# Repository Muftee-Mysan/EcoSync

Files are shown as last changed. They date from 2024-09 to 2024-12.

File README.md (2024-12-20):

# ECOSYNC: Smart Energy Solution for Hotels

ECOSYNC is an innovative energy-saving solution tailored for the hotel industry. Our system bridges the gap between energy efficiency and guest comfort, addressing key challenges faced by hotels in managing air conditioning systems effectively.

---

## Problem Statement

Hotels often struggle to balance energy efficiency with guest comfort:
- **Keycard Systems** save energy but leave rooms uncomfortably warm for returning guests.
- **Keeping AC On** ensures comfort but wastes energy significantly.

### Our Solution
ECOSYNC optimizes energy usage by dynamically adjusting the air conditioning:
- When the keycard is **removed**, the AC temperature rises to conserve energy without causing discomfort.
- Upon **insertion**, the AC restores the initial, lower temperature for guest comfort.

---

## Key Features

- **Dual PCB Design**: Separate units for Keycard Presence Detection (KPD) and AC Control (ACC).
- **Bluetooth Communication**: Reliable, cost-effective signal exchange between KPD and ACC.
- **Energy Efficiency Modes**:
  - *Eco Mode*: Sets temperature to 25°C (indicated by a green LED).
  - *Luxury Mode*: Sets temperature to 23°C (indicated by a blue LED).
- **IR Sensors**: Detect keycard presence and transmit relevant signals to the AC.
- **Customizable Calibration**: Tailored implementation for each hotel room's air conditioning unit.

---

ecosyn final

## Technical Details

### Components Used
- **Microcontroller**: ATmega328P-PU
- **Bluetooth Modules**: HC-05 & HC-06
- **IR Proximity Sensor**: Detects keycard presence
- **IR Emitter**: Transmits AC temperature adjustment signals
- **Power Supply**: DC-DC Buck Converter with 3.7V rechargeable batteries

ECOSYNC has two seperate units
### 1. **Keycard Presence Detector (KPD)**
   - The KPD unit is a keycard holder equipped with an IR proximity sensor.
   - **Functionality**: 
     - Detects when the keycard is inserted or removed.
     - Sends a signal to the AC Controller (ACC) via Bluetooth when the keycard is removed.

### 2. **AC Controller (ACC)**
   - The ACC receives the signal from the KPD and adjusts the AC settings based on the mode selected.
   - **Modes**:
     1. **Eco Mode**:
        - Temperature is raised to 25°C.
        - Green LED indicates the Eco Mode is active.
     2. **Luxury Mode**:
        - Temperature is raised to 23°C.
        - Blue LED indicates the Luxury Mode is active.
   - The mode selection is manual and can be controlled by the hotel management.

---

## Future Improvements

- **IoT Integration**: Upgrade to Xtensa LX6 microprocessor for Wi-Fi and Bluetooth capabilities.
- **Mobile Automation**: Control via a dedicated app.
- **AI Scheduling**: Personalized temperature adjustments based on user behavior.
- **Voice Control**: Integration with virtual assistants for enhanced convenience.
- **Air Quality Enhancements**: Address CO2 levels with advanced ventilation systems.

---

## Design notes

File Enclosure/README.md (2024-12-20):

### Enclosure Design
The enclosures were designed to ensure durability, aesthetic appeal, and ease of integration:
- **Material**: 3D-printed plastic for lightweight and customizable builds.
- **Features**:
  - Compact housing for PCB components.
  - Openings for LED indicators, keycard slot, and connectors.
  - Sleek design to blend seamlessly into hotel room decor.

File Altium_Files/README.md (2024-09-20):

### Altium PCB Design Files

We have used **Altium Designer** to create the printed circuit board (PCB) designs for our project. The files in this directory include the **schematic** and **PCB layouts** for two specific designs:

1. **AC Controller**
2. **Key Card Presence Detector**

#### Design Details:

- Both PCBs were designed using a **two-layer** approach, with **top** and **bottom** layers.
- During the design process, we referred to the **datasheets** of all the components to ensure accurate specifications and proper functionality.

These designs are crucial for controlling the air conditioning system and detecting key card presence, contributing to energy efficiency and automated room control in our project.

pcb

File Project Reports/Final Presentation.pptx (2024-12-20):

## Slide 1

SocketBurners
Aashir MRM
220004M
Muftee MMM
220399B
Munavvar MAA
220405T
Nadha MI
220409J

EcoSync
“Enhancing Comfort, Conserving Power, Innovating the Future”
Intelligent AC Temperature Regulator

EN1190 – Engineering Design Project

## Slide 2

The Problem

“Energy Wastage due to lack of optimization in luxurious hotels.”

User leaves
the hotel room with
the keycard

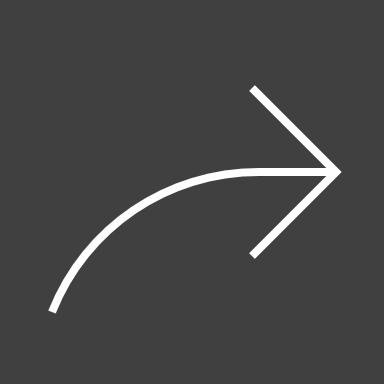
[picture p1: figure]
Back outline

Cut the power
to the room while
Keeping the AC running

1

Waste of Energy

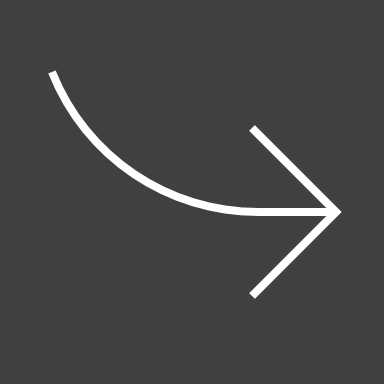
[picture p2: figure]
Back outline

Cut the entire
power supply

2

User discomfort
upon arrival

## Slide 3

The Solution

A compromise between visitor comfort and energy usage is required.
To accomplish this, we present to you

EcoSync
“Enhancing Comfort, Conserving Power, Innovating the Future”
Intelligent AC Temperature Regulator

ECOSYNC regulates the air conditioning system based on user presence.

The Beneficiary

Luxurious Hotel chains
&
The people of Sri Lanka

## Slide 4

Designing the Solution

The Concept
Breadboard Implementation
PCB Design
Enclosure Design
Assembly

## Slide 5

Problem Validation
Hotel Visit: Sofia Colombo

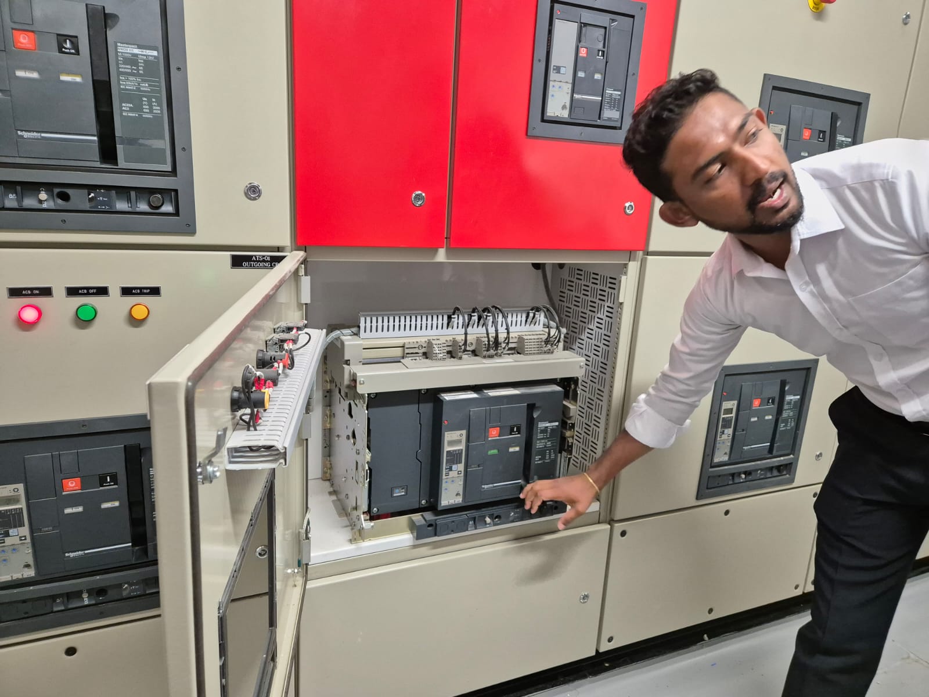
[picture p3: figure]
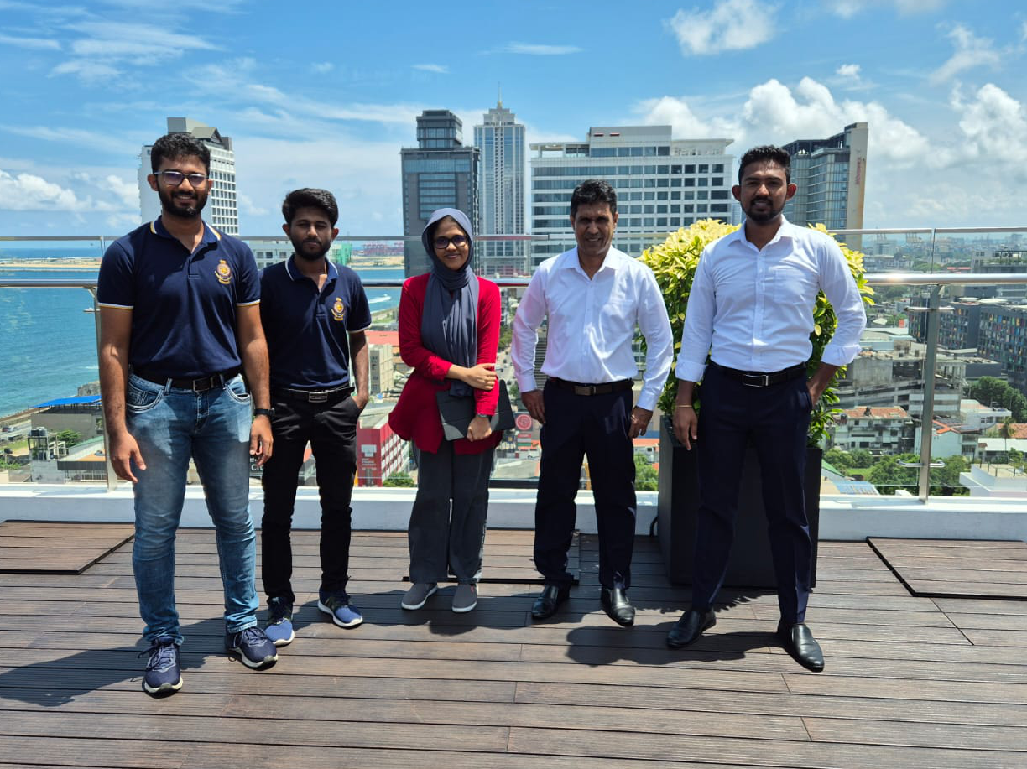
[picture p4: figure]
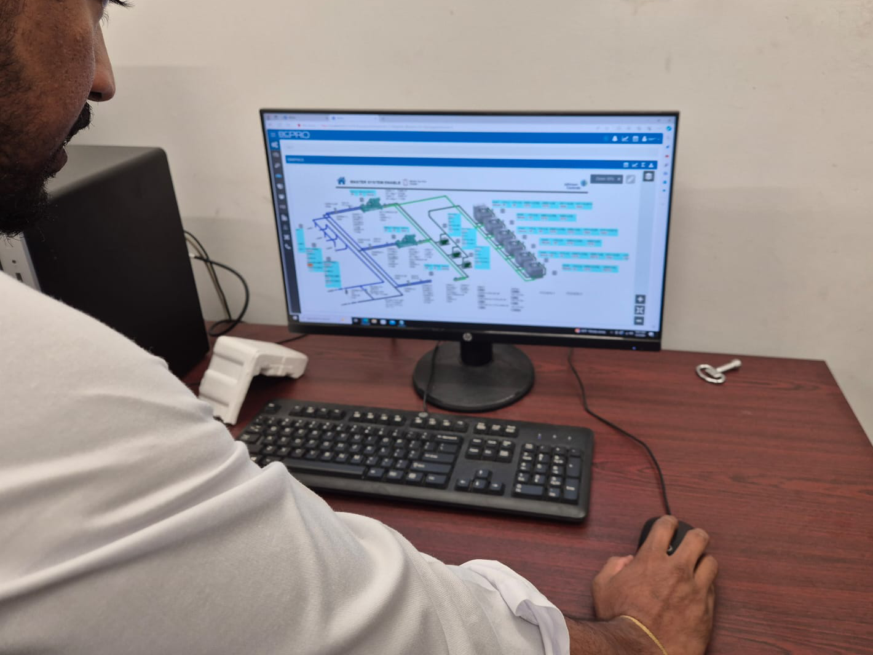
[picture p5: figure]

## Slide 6

Block Diagram of the Concept

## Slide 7

Functionality

ECOSYNC is a combination of two separate units
1. KPD: Keycard Presence Detector
2. ACC: Air Conditioner Controller

KPD

When the Keycard is removed, (Person Left the room)

The relevant IR signals are sent to the AC

ACC

Eco Mode: Temperature rises to 25°C
Luxury Mode: Temperature rises to 23°C

The message gets transmitted to ACC through Bluetooth

The ACC receives the message

Preset by hotel management

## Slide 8

The PCB Design
ACC

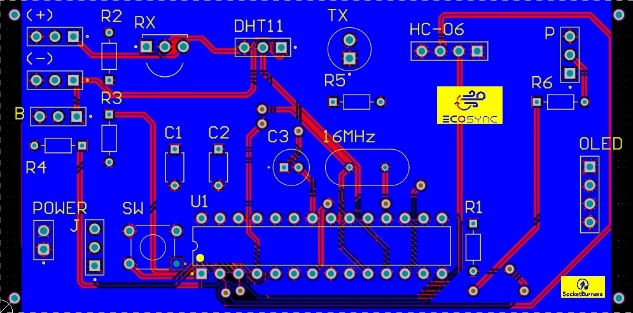
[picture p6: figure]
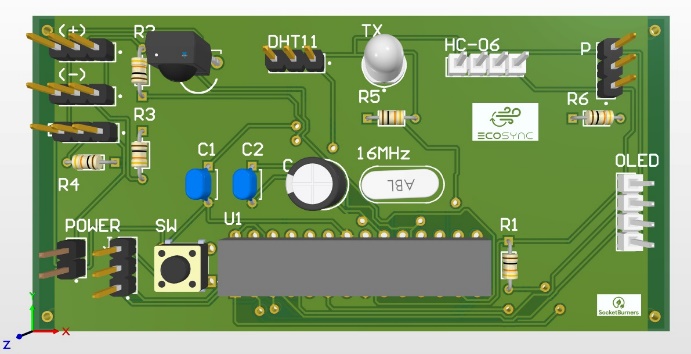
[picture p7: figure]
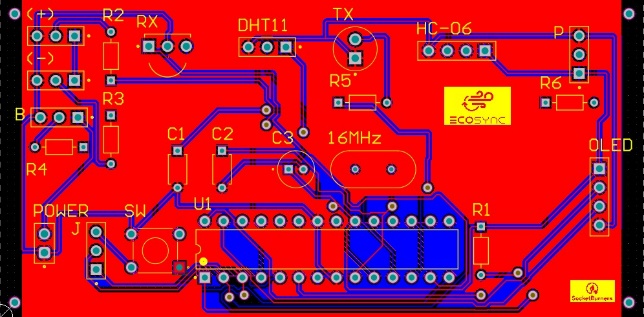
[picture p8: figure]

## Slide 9

The PCB Design
KPD

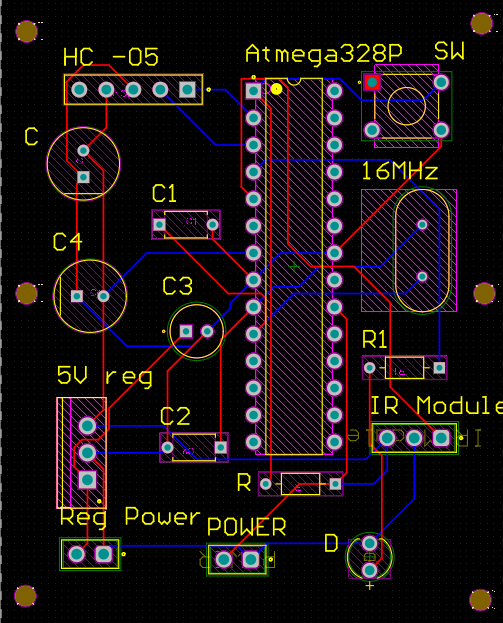
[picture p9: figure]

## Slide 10

The Enclosure Design
ACC

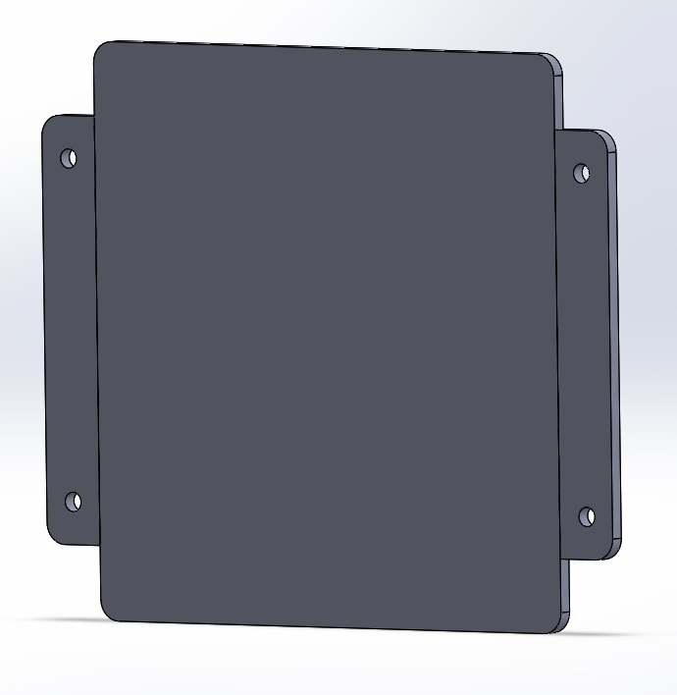
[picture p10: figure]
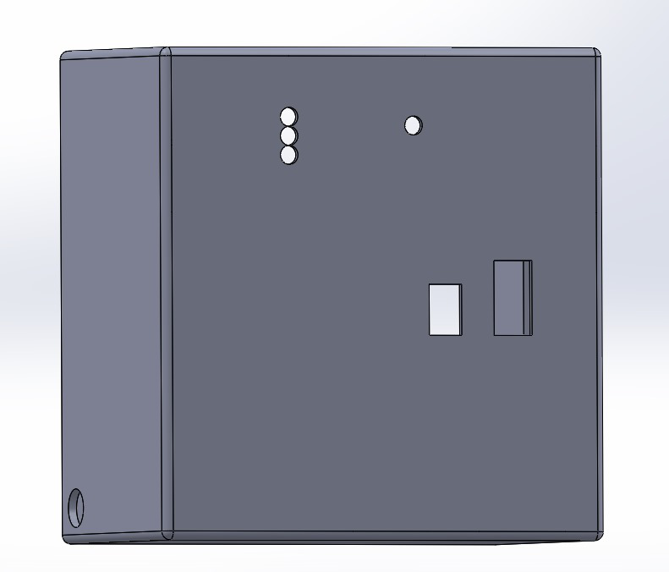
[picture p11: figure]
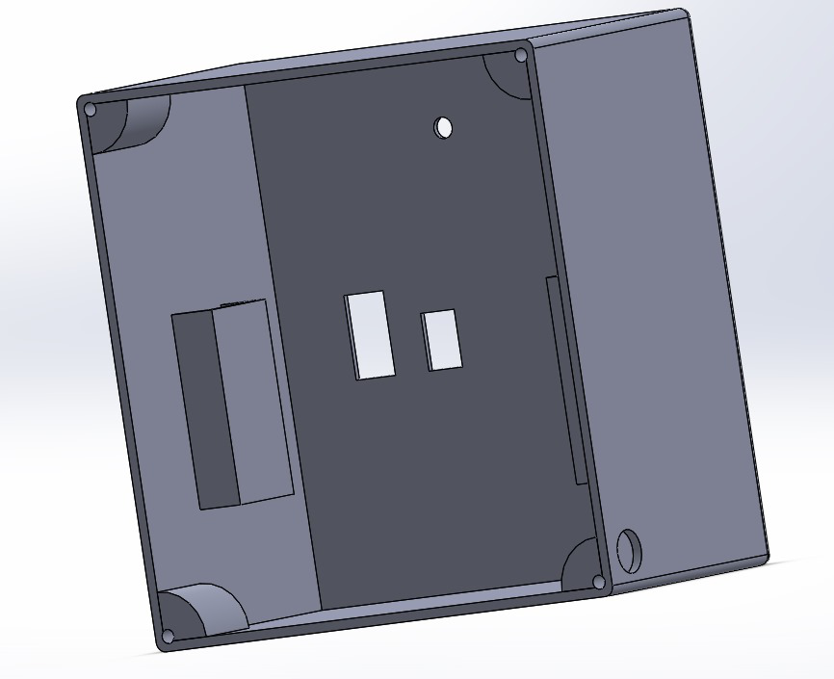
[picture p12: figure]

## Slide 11

The Enclosure Design
KPD

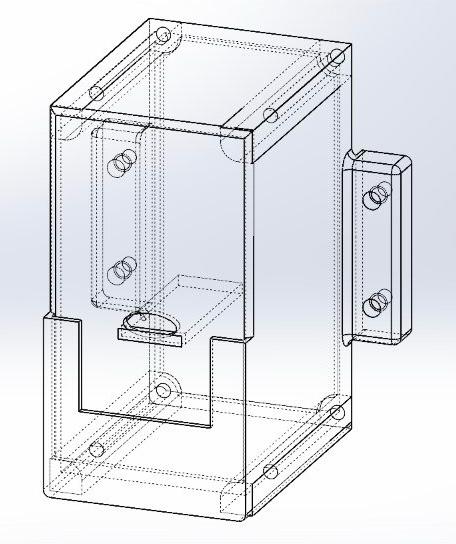
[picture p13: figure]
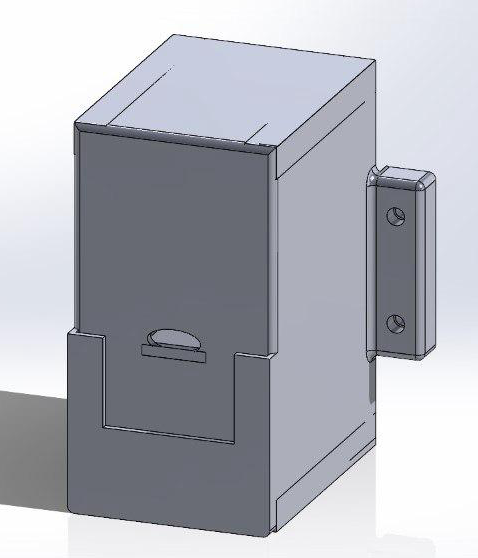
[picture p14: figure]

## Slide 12

The Assembly

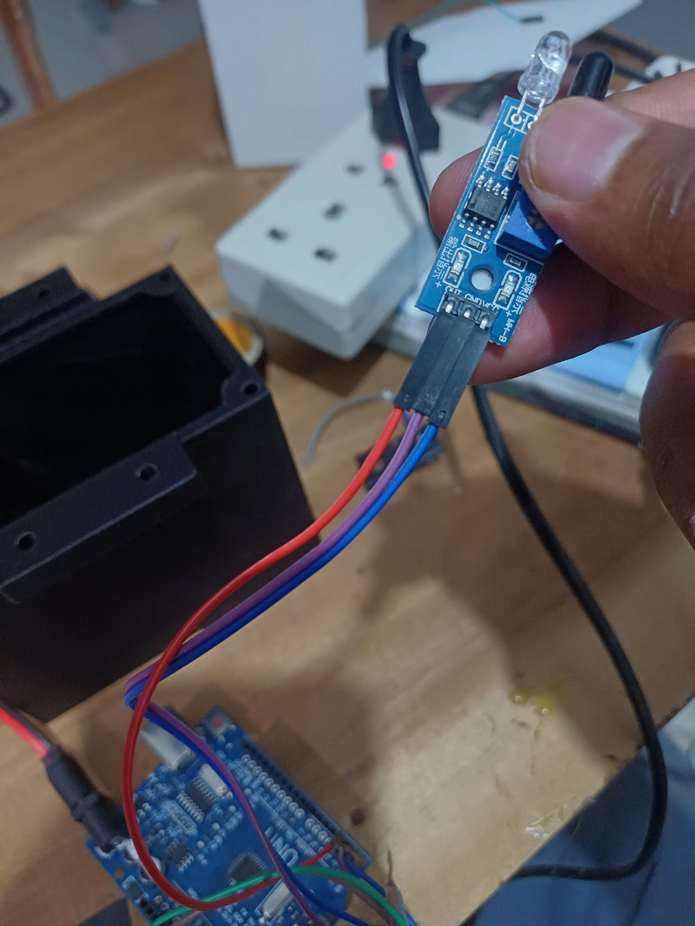
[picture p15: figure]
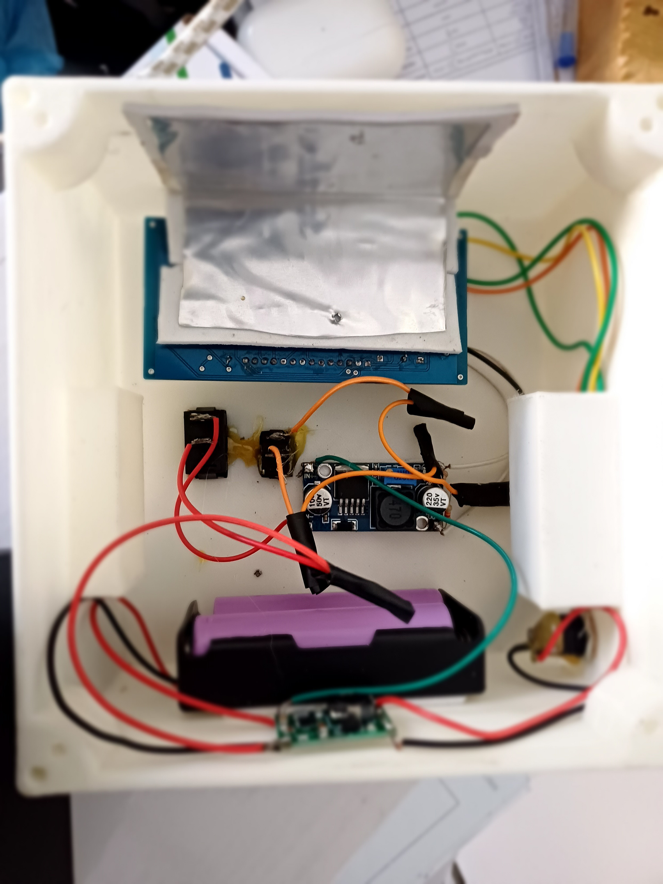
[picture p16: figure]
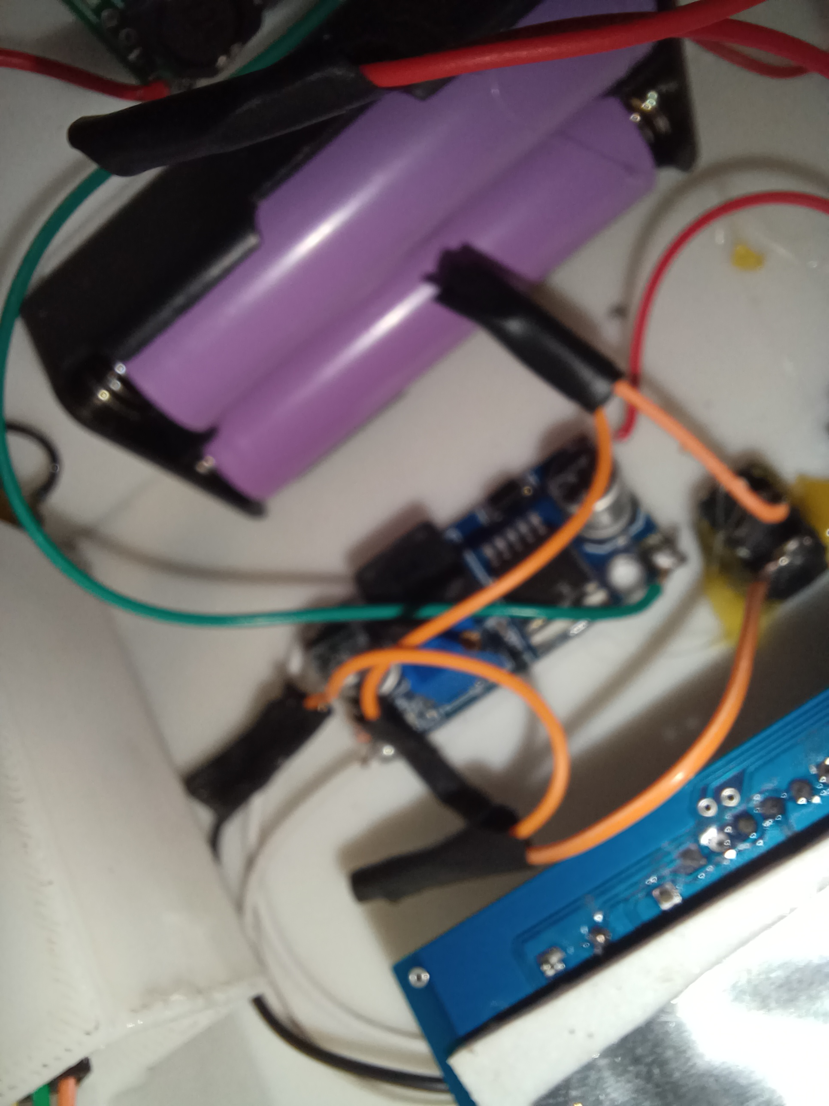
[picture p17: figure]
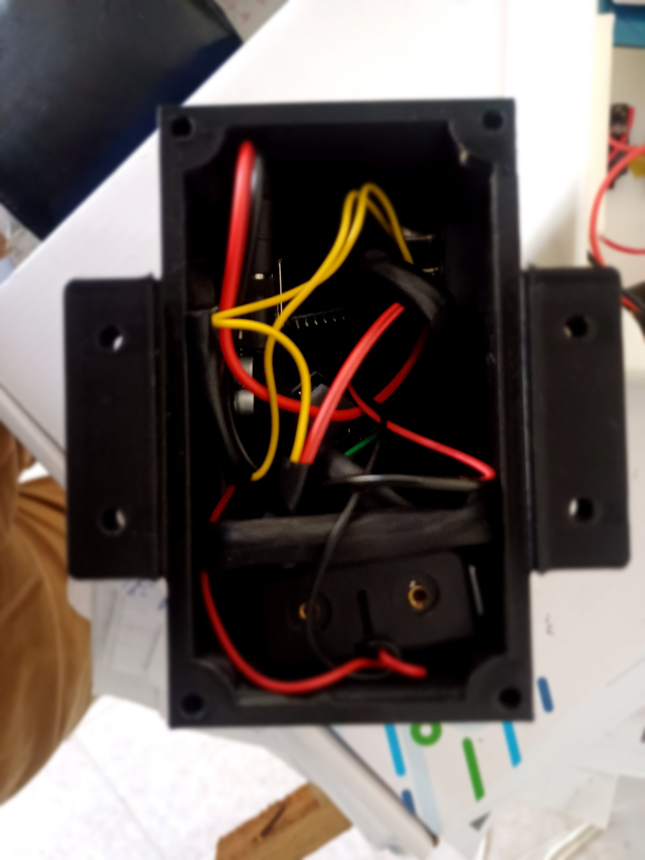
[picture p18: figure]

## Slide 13

The Final Product

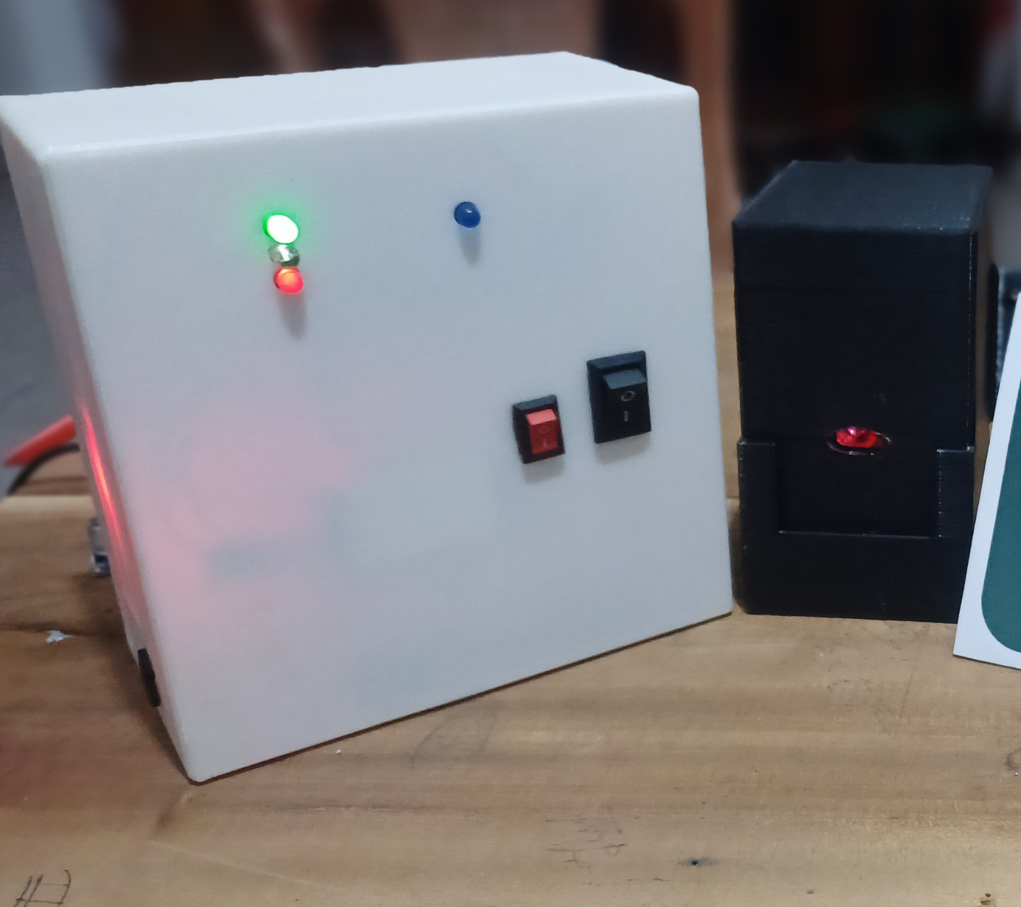
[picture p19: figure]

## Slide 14

Our Website

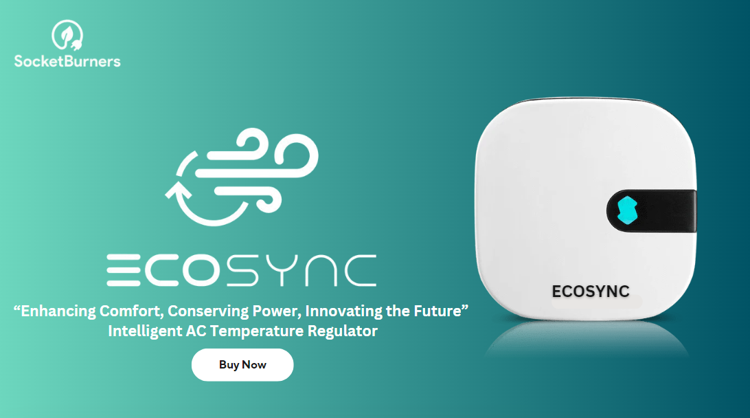
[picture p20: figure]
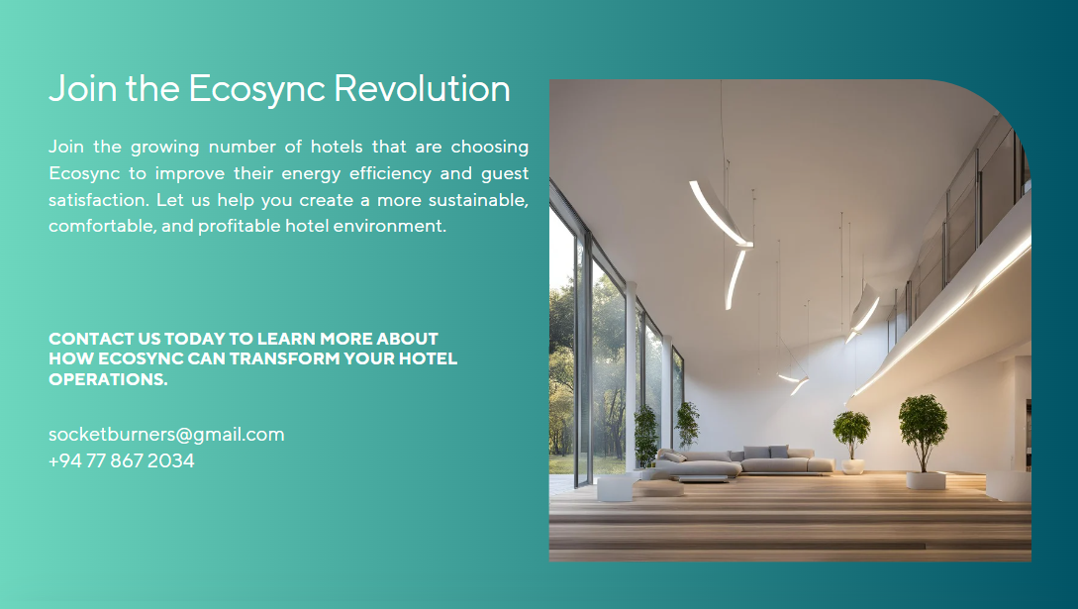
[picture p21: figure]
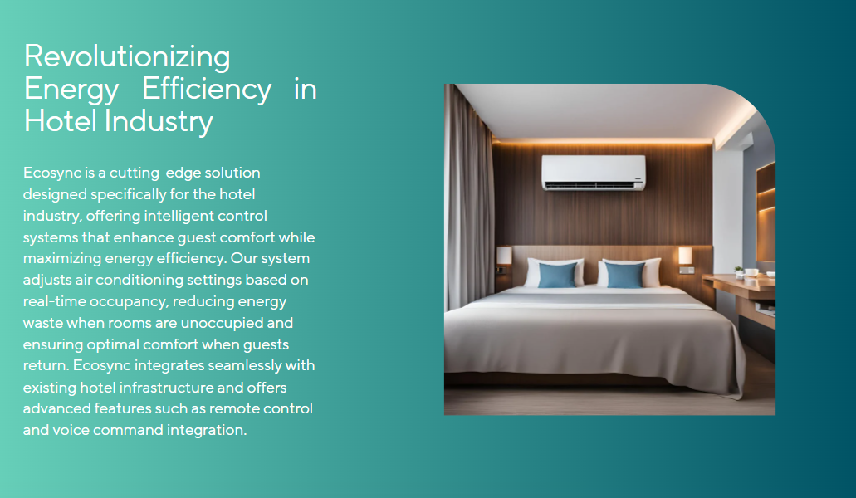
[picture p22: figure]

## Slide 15

Project Budget

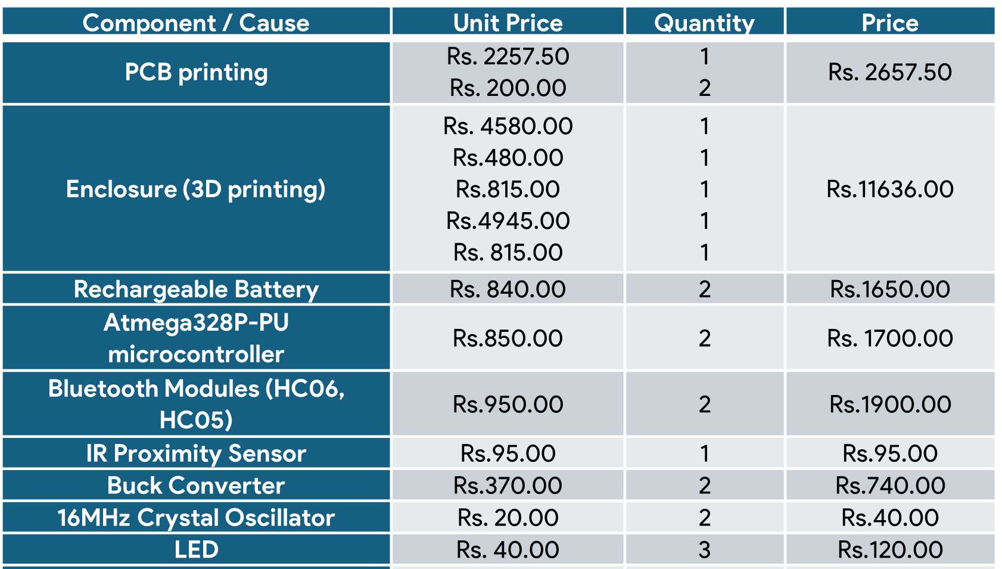
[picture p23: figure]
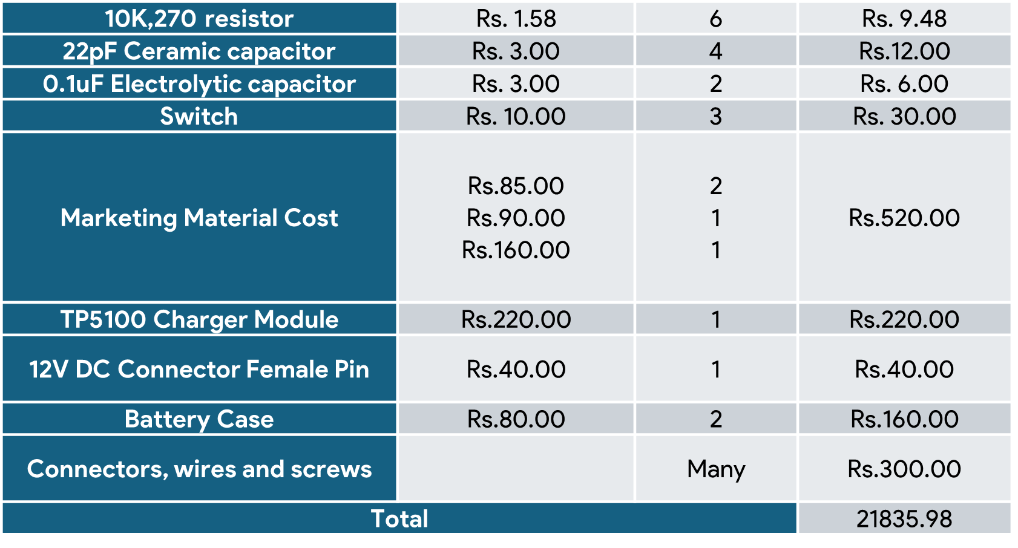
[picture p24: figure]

Rs.21835.98

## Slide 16

Task Delegation

TASK | ALLOCATED MEMBER(S)
Finding a problem | ALL
Solution plan | ALL
Circuit Diagrams | Muftee MMM Aashir MRM
PCB design | Nadha MI
Programming and coding the controller | Aashir MRM
Enclosure design | Muftee MMM
Product assembly | Aashir MRM Munavvar MAA
Documentation Preparations | Munavvar MAA Nadha MI
Brand design | Munavvar MAA
Web Page Design | Nadha MI

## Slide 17

The Team
SocketBurners

Aashir MRM
220004M

Munavvar MAA
220405T

Muftee MMM
220399B

Nadha MI
220409J

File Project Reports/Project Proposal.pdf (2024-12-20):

# Project Proposal


# EcoSync

“Enhancing Comfort, Conserving Power, Innovating the Future”

### Intelligent AC Temperature Regulator

## SocketBurners

Aashir MRM
220004M

Muftee MMM
220399B

Munavvar MAA
220405T

Nadha MI
220409J

EN1190 – Engineering Design Project

One of the major concerns in today's industrial world is the energy deficit. This brings various challenges to energy consumption due to rising energy costs & wastage.
Hotels have implemented a key card system that automatically switches off the electricity when guests leave their rooms to conserve energy. However, upon returning to their rooms, guests often experience discomfort due to the temperature rise and must manually adjust the air conditioner. However, some hotels keep the air conditioner running even after removing the key card to ensure guest comfort, leading to significant energy wastage.
As an effective solution for this problem, we came up with the idea: “EcoSync.”

which adjusts the AC level without turning it off based on the presence of guests as a practical solution to optimize energy usage while maintaining guests’ comfort.

The standard temperature range for air conditioners when the user is present in the room is typically between 18 to 20 degrees Celsius.
When the keycard is removed, the ECOSYNC system will automatically adjust the AC temperature to a higher level around 27-28 degrees Celsius. This feature can help save energy consumption by up to 50% - 70%. Once the Keycard is inserted again, the system will automatically return to the initial lower temperature levels.
It prevents user discomfort and at the same time conserves energy.
Introduction | Concept
1. Check whether the keycard is inserted or not.
2. Send the signal to the controller’s receiver.
3. Emit the IR rays from the controller to the AC’s IR receiver to change the temperature.
4. Send data to the Cloud Network.

## Implementation Objectives

1. PCB with Controller
2. 2 Transceivers
3. An IR Emitter
4. A Wi-Fi Microchip
5. Power Supply

## Resources

Target Scope:
We mainly focus to establish a market in the luxury hotel field where the keycard system is in use. Expected Outcome:
Reducing nation’s energy wastage.
(Offering high quality customer service in the hotel industry)

## Expected Scope and Outcome

# EcoSync |

Air Conditioner
System

Product Description
Ecosync is a smart A/C regulator designed to be used in luxurious hotels. Its primary function is to maintain the A/C temperature at an optimum level (i.e: A level at which both user comfort and energy usage are considered)
Problem Validation
- Sri Lanka’s point of view.
Sri Lanka is going through unprecedented times. The economic crisis continues to worsen on one side and on the other side we have a shortage of energy supply to meet current energy demands. Amidst this status quo, it's imperative for us as a nation to do everything possible to preserve energy and to impose regulations to mitigate energy wastage. Therefore, it is in the best interest of the country to have regulations in place to control energy usage in luxurious hotels. In this context, our solution comes in handy since our proposed solution cuts down energy used by the air conditioning system by 50 %. This creates a huge incentive for hotels to consider our product.
- Energy Regulations set by the government.
Hotels must follow energy regulations that aim to promote sustainability and reduce environmental impact. These regulations cover different aspects like energy efficiency standards, renewable energy utilization, and energy conservation measures. Hotels are required to meet specific standards for lighting, AC systems, and appliances.
- Global point of view.
Sustainable Development Goal 7 (SDG7) calls for “affordable, reliable, sustainable and modern energy for all” by 2030. The world collectively is promoting measures to achieve sustainable energy. Through our product, we can conserve valuable energy.
In addition, hotels are also incentivized by this. They can earn tax benefits, be nominated for awards, etc... for demonstrating sustainable practices. This is a win-win for our proposed solution.
- Luxury Hotels’ point of view.
The hotels that are under consideration here are in the business for money. They look for ways to increase their profits. While having to abide by government regulations, promote an eco-friendly image, and strive to achieve UN sustainability goals are within the Hotel’s mandate, there is something else that interests them more, which is profit. This is where we come into the picture. As per the tariff approved by the Public Utilities Commission of Sri Lanka, hotels are charged 25 LKR/kWh for energy consumption between 0-180 kWh, and 36 LKR/kWh for energy consumption above 180 kWh. This leads to a fourfold increase in the monthly charge.
Reference: https://www.pucsl.gov.lk/electricity/tariff/industrial-consumers/

By cutting down the energy consumption by 52% using our product, we can bring down the costs by more than 50%. This is extremely beneficial for these hotels, which in turn creates demand for our product.

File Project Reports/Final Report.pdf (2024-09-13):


## University of Moratuwa

### Faculty of Engineering

Department of Electronic and Telecommunications Engineering

EN1190 – Engineering Design Project


# Final Report

by

Aashir MRM Muftee MMM Munavvar MAA Nadha MI

ECOSYNC | SocketBurners
- 1 -

## Table of Contents

| - 0 -
1 | Problem Description and Solution | - 3 -
1.1 | Problem Identification | - 3 -
1.2 | Proposed Solution | - 3 -
2 | Technical Feasibility | - 3 -
2.1 | ATmega 328P-PU Microcontroller | - 3 -
2.2 | Power Supply Unit | - 4 -
2.3 | LM2596S and DC to DC Buck Converter Modules | - 4 -
2.4 | HC-05, HC-06 Bluetooth Wireless Serial Arduino Modules | - 5 -
2.5 | IR Proximity Sensor Module | - 5 -
2.6 | IR Emitter | - 6 -
3 | Product architecture | - 6 -
3.1 | AC Controller | - 6 -
3.2 | Keycard Presence Detector | - 7 -
4 | PCB Design | - 7 -
4.1 | AC CONTROLLER | - 8 -
| - 8 -
4.2 | KEY CARD PRESENCE DETECTOR | - 9 -
5 | Enclosure Design | - 9 -
5.1 | Design Sketches | - 9 -
5.2 | Final enclosure design | - 10 -
6 | The Final Product | - 10 -
7 | Marketing Approach | - 11 -
7.1 | Target Audience | - 11 -
7.2 | Unique Selling Point | - 11 -
7.3 | Marketing Strategy | - 11 -
7.3.1 | Digital Marketing Strategy | - 11 -
7.3.2 | Sales Strategy | - 11 -
7.3.3 | Promotional Activities | - 11 -
7.4 | Brand Design | - 12 -
8 | Bill of Quantities | - 13 -

- 2 -
9 | Revenue Streams | - 13 -
10 | Task Delegation | - 14 -
11 Functioning of the device prototype | - 14 -
12 | Future Improvements | - 15 -
12.1 | Development of the second prototype | - 15 -
12.2 | Mobile Automation | - 15 -
12.3 | Automatic scheduling | - 15 -
12.4 | Voice command functionality | - 15 -
12.5 | Research and development: addressing CO2 increase | - 15 -

- 3 -

## 1 Problem Description and Solution

## 1.1 Problem Identification

In today's industrial world, one of the major concerns is the energy deficit, leading to rising energy costs and significant wastage. The hotel industry exemplifies this challenge, as it struggles to balance energy efficiency with guest comfort.

Many hotels have implemented a key card system to automatically switch off electricity when guests leave their rooms, aiming to conserve energy. However, this solution is not without its flaws. When guests return, they often find their rooms uncomfortably warm and must manually readjust the air conditioning, leading to dissatisfaction. On the other hand, to ensure guest comfort and protect room furnishings, some hotels keep the air conditioning running even after removing the key card. While improving the guest experience, this practice results in considerable energy wastage.

Therefore, the hotel industry faces a critical dilemma: achieving energy efficiency without compromising guest comfort. Our startup aims to address this pressing issue by developing an innovative solution that refines energy consumption while maintaining a comfortable environment for hotel guests.

## 1.2 Proposed Solution

It is obvious that turning off and keeping the AC on are problematic. Therefore, we proposed a solution, a device called “ECOSYNC” to achieve the state between two extremes.

When the keycard is removed from the holder (indicating the user’s absence), ECOSYNC increases the AC temperature to a higher value to minimize power consumption. This higher value of the temperature will not make the user uncomfortable either. When the keycard is inserted again the initial low temperature will be obtained. \

## 2 Technical Feasibility

We use several fundamental modules to achieve the feasibility of the product. especially we designed ECOSYNC to have two separate PCB units: Keycard Presence Detector and AC Controller.

## 2.1 ATmega 328P-PU Microcontroller

We chose to use this microcontroller chip because of its flexibility in choosing internal and external clock sources and ease of programmability. We use two of these chips for both PCBs. It functions as the main controller for the whole ECOSYNC.


- 4 -

## 2.2 Power Supply Unit

Since we have two separate PCB units, each needs separate power supply units too. We used two 3.7V rechargeable batteries for both systems. We chose a higher voltage supply for efficiency.

ACC comes with a 12V DC charger, which can be kept connected without needing to charge manually often. The battery pack takes a minimal amount (~5mA) to achieve this specification.

## 2.3 LM2596S and DC to DC Buck Converter Modules

A buck converter is essential to step down, regulate, and stabilize the supplied voltage since we use a high-voltage power supply.


- 5 -

## 2.4 HC-05, HC-06 Bluetooth Wireless Serial Arduino Modules

HC-05 acts as the transmitter from the Keycard Presence Detector and HC-06 is the receiver, which is placed in the AC Controller unit. We had to use two separate modules because, though HC-05 can function as both transmitter and receiver; HC-06 can only receive Bluetooth signals. The transmitter sends the information about the keycard’s presence in the keycard holder to the

receiver. This plays the vital role of triggering the AC Controller to change the temperature of the AC.

Since both units of ECOSYNC are inside a room, we chose Bluetooth modules to communicate with each other, which is cost-effective too.

## 2.5 IR Proximity Sensor Module

ECOSYNC’s one of the main tasks is to detect the Keycard’s presence. To achieve this, we could use several proximity sensors; though we stuck with this IR module because it is very flexible and cost-effective, also it fulfills the requirements.

MICROCONTROLLER UNIT; IR RECIEVER; IR TRANSMITTER; BLUETOOTH MODULE; POWER SUPPLY UNIT; INDICATOR LEDs; CHARGER MODULE

- 6 -

## 2.6 IR Emitter

ECOSYNC’s other main task is to change the temperature of the AC according to the presence of the keycard. It achieves this by emitting relevant IR signal arrays. We use a basic IR Emitter to complete this task.

## 3 Product architecture

The block diagram of the proposed product architecture is as follows

## 3.1 AC Controller

- 7 -

## 3.2 Keycard Presence Detector

## 4 PCB Design

We have used Altium software to design our PCB. The following are the schematic and PCB layouts that we developed. During our development procedure, we referred to data sheets of the components used to find their specifications.

MICROCONTROLLER
UNIT
IR SENSOR | BLUETOOTH MODULE

POWER SUPPLY
UNIT

## 4.1 AC CONTROLLER


- 8 -

Schematic of the PCB

Top layer

Bottom layer

## 4.2 KEY CARD PRESENCE DETECTOR


- 9 -

## 5 Enclosure Design

## 5.1 Design Sketches

Schematic of the PCB

## 5.2 Final enclosure design


- 10 -

## 6 The Final Product

- 11 -

## 7 Marketing Approach

## 7.1 Target Audience

ECOSYNC initially targets luxury hotels that are committed to guest comfort and sustainability. These high-end establishments prioritize offering a luxurious experience while adhering to stringent environmental standards. As we expand our market presence, we will consider the unique requirements of Mid-range hotels, hotel chains, and Boutique hotels. This approach ensures that ECOSYNC not only meets the current needs of luxury hotels but also adapts to the diverse demands of other hotel segments in the future.

## 7.2 Unique Selling Point

Normally the electricity bill of a hotel surpasses millions per month, after several meetings with some hotels, we got to know their main interest in our product is that ECOSYNC can save a significant amount on the electricity bill. We consider that as our main and unique selling point.

## 7.3 Marketing Strategy

To kickstart our efforts, we gathered data on hotel owners’ and managers’ priorities and challenges related to energy management through Surveys, field visits, and Industry reports. This research also encompassed competitor analysis to highlight ECOSYNC's unique advantages. Studies related to existing solutions, their strengths, and weaknesses were conducted to ensure ECOSYNC stands out in the market.

### 7.3.1 Digital Marketing Strategy

Digital marketing will play a crucial role, targeting social media campaigns on platforms like LinkedIn, Facebook, and Instagram. These campaigns will engage industry professionals. Email marketing campaigns will be tailored to hotel owners and managers, highlighting the cost-saving and comfort-enhancing benefits of ECOSYNC.

### 7.3.2 Sales Strategy

Direct sales will be driven by a resolute sales team, complemented by online sales through our website. We will also focus on strategic partnerships with HVAC companies and hotel suppliers to broaden our distribution network and enhance product integration.

### 7.3.3 Promotional Activities

- Product demonstrations
- Webinars
- Participation in hotel industry trade shows and conferences


- 12 -

These activities will highlight ECOSYNC's capabilities and allow us to network with potential clients and partners.

## 7.4 Brand Design

The brand name is “ECOSYNC,” and we use that to mention our product in every single instant. We have created a logo that describes our product’s functionality. We made flyers along with some stickers that simply explained the function of the product.

- 13 -

## 8 Bill of Quantities

Component / Cause | Unit Price | Quantity | Price
PCB printing | Rs. 2257.50 Rs. 200.00 | 1 2 | Rs. 2657.50
Enclosure (3D printing) | Rs. 4580.00 Rs.480.00 Rs.815.00 Rs.4945.00 Rs. 815.00 | 1 1 1 1 1 | Rs.11636.00
Rechargeable Battery | Rs. 840.00 | 2 | Rs.1650.00
Atmega328P-PU microcontroller | Rs.850.00 | 2 | Rs. 1700.00
Bluetooth Modules (HC06, HC05) | Rs.950.00 | 2 | Rs.1900.00
IR Proximity Sensor | Rs.95.00 | 1 | Rs.95.00
Buck Converter | Rs.370.00 | 2 | Rs.740.00
16MHz Crystal Oscillator | Rs. 20.00 | 2 | Rs.40.00
LED | Rs. 40.00 | 3 | Rs.120.00
10K,270 resistor | Rs. 1.58 | 6 | Rs. 9.48
22pF Ceramic capacitor | Rs. 3.00 | 4 | Rs.12.00
0.1uF Electrolytic capacitor | Rs. 3.00 | 2 | Rs. 6.00
Switch | Rs. 10.00 | 3 | Rs. 30.00
Marketing Material Cost | Rs.85.00 Rs.90.00 Rs.160.00 | 2 1 1 | Rs.520.00
TP5100 Charger Module | Rs.220.00 | 1 | Rs.220.00
12V DC Connector Female Pin | Rs.40.00 | 1 | Rs.40.00
Battery Case | Rs.80.00 | 2 | Rs.160.00
Connectors, wires, and screws | | Many | Rs.300.00
Total | | | 21835.98

## 9 Revenue Streams

Subscription-Based Model: Recurring revenue from subscription fees for the use of the ECOSYNC system, including software updates and support services.

Installation Fees: One-time revenue from the first installation and integration of the system into the hotel’s infrastructure.

Consulting Services: Added revenue from offering energy efficiency consulting services to help hotels maximize the benefits of the system.

- 14 -

Partnership Revenue: Revenue-sharing agreements with strategic partners who promote and integrate ECOSYNC’s solutions into their offerings.

## 10Task Delegation

Done in a manner that tasks are equally divided resulting in an evenly spread workload.

Though tasks are divided, as a team we helped each other in every other’s task.

TASK | ALLOCATED MEMBER(S)
Finding a problem | ALL
Solution plan | ALL
Circuit design | Muftee MMM Aashir MRM
PCB design | Nadha MI
Programming and coding the controller | Aashir MRM
Enclosure design | Muftee MMM
Product assembly | Aashir MRM Munavvar MAA
Documentations | Munavvar MAA Nadha MI
Brand design (Logo, brochures) | Munavvar MAA

## 11 Functioning of the device prototype

ECOSYNC has two separate units.

- Keycard Presence Detector (KPD): A keycard holder with a presence detector.
- AC Controller (ACC)

KPD’s IR proximity sensor detects whether the keycard is inserted or removed if it is removed,

It sends the message to the ACC using a Bluetooth signal. ACC then transmits relevant IR signals to the AC according to the selected mode to change the working temperature of the AC.

ACC has two modes,

- Eco Mode: Rises the temperature to 25 degrees Celsius; showed by green LED
- Luxury Mode: Rises the temperature to 23 degrees Celsius; showed with blue LED

The mode selection is designed to be manual and can be controlled by the hotel management.

- 15 -
- ECOSYNC works only with the implemented hotel room’s air conditioner.
The calibrations for each air conditioner will be done during the implementation process.

## 12 Future Improvements

## 12.1 Development of second prototype

We are planning to upgrade our hardware components to the Xtensa LX6 microprocessor, which will significantly enhance the Wi-Fi and Bluetooth integration capabilities of our product. This upgrade will allow us to incorporate advanced IoT functionalities, providing a more connected and seamless experience for our users.

## 12.2 Mobile Automation

ECOSYNC will offer seamless control through an intuitive mobile app, allowing users to adjust A/C settings from anywhere. This ensures that guests can maintain their preferred comfort levels effortlessly.

## 12.3 Automatic scheduling

Powered by innovative AI, ECOSYNC will learn user preferences and behaviors to optimize temperature settings automatically. This feature will maintain comfort while minimizing energy usage by adjusting settings based on a personalized schedule.

## 12.4 Voice command functionality

As an additional luxury feature, we are also developing voice command functionality like Alexa on smart home devices. This feature will allow guests to control the air conditioning and other room settings using simple voice commands, enhancing their overall experience, and adding a modern, convenient touch to their stay.

## 12.5 Research and development: addressing CO2 increase

During ECOSYNC's research phase, we are tackling the challenge of increased CO2 levels inside hotel rooms. Elevated CO2 can cause health issues such as headaches, dizziness, fatigue, and impaired cognitive performance. Poor air quality can exacerbate respiratory conditions and disrupt sleep patterns, negatively impacting guest satisfaction and overall comfort.

To mitigate these effects, we are exploring advanced ventilation systems and air purifiers integrated with CO2 sensors. These systems will monitor air quality in real-time and automatically adjust ventilation to maintain optimal levels. For AC units without built-in ventilation, ECOSYNC will provide warnings to increase ventilation. Our goal is to enhance energy efficiency and significantly improve indoor air quality, ensuring a healthier and more comfortable environment for hotel guests.
